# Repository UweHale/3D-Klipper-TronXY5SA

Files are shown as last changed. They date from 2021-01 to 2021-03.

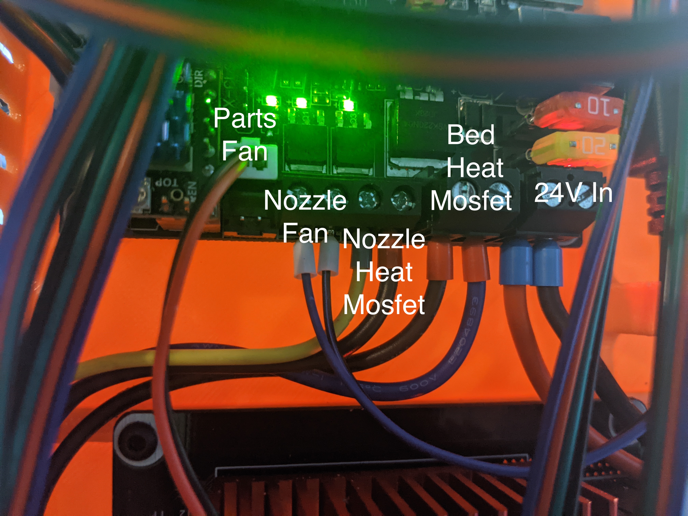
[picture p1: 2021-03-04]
SKR-Power-Fan.jpg

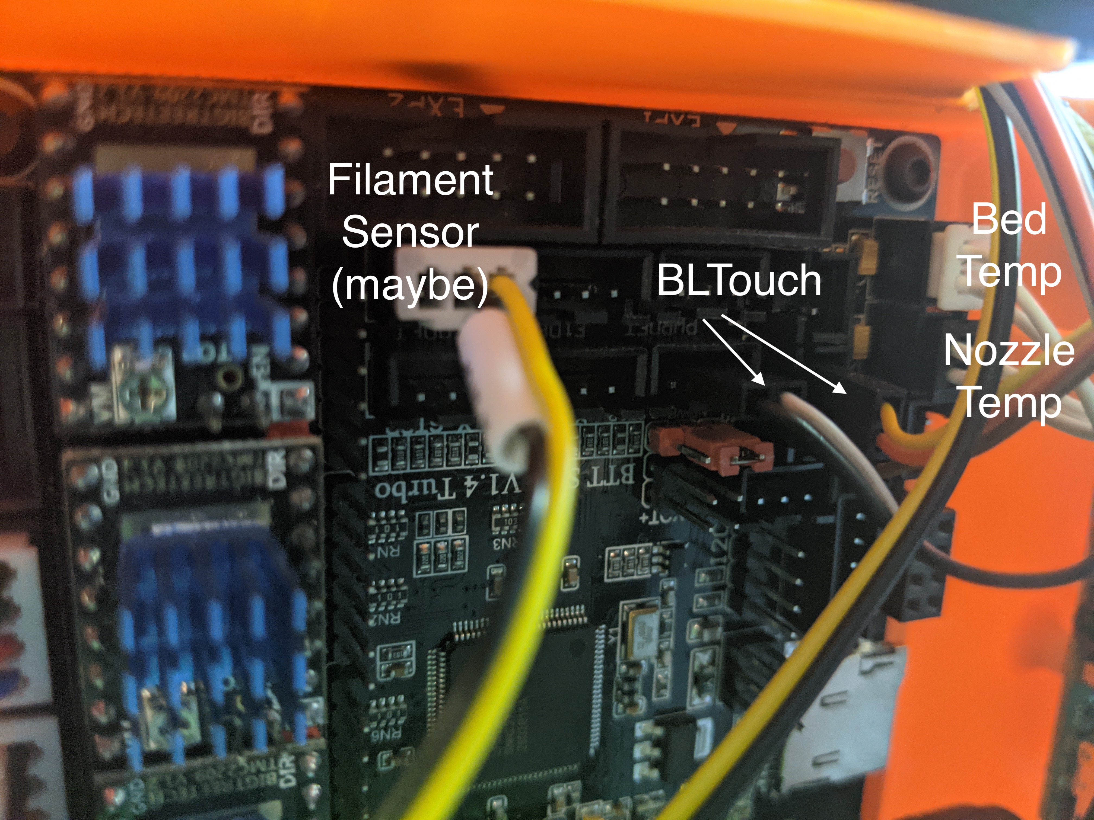
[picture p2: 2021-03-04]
SKR-Sensors.jpg

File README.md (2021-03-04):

# 3D-Klipper-TronXY5SA

Modifying a TronXY5SA to use a SKR 1.4 Turbo board and a Raspberry PI running OctoPi and Klipper.

STL and Fusion 360 file for a custom case to hold it all.

Be sure you have good thermal control.  The case can warp and lift off the bed if cooled too rapidly.  You might need to turn on supports for the corner screw blocks for a lid.

The Z adjust blocks are spacers for doing the initial Z sync on the stepper motors.  Put one on each side and bottom out (stall the motors) the bed rails.  Lower bed, remove and continue 

Carriage bracket for BMG Direct Extruder and a Dragon Hotend with BLTouch.

Use supports for the parts fan.  The BMG extruder mount does not need supports.  I printed mine with PETG. 

Power supply is a MEAN WELL RSP-500-24
https://smile.amazon.com/gp/product/B00UWCD22O

Designed with 50mm centrifugal fans from Winsinn
https://smile.amazon.com/gp/product/B07DB7DLMM

BCZAMD 3D Printer Heating Controller MKS MOSFET
https://smile.amazon.com/gp/product/B07R292KXF

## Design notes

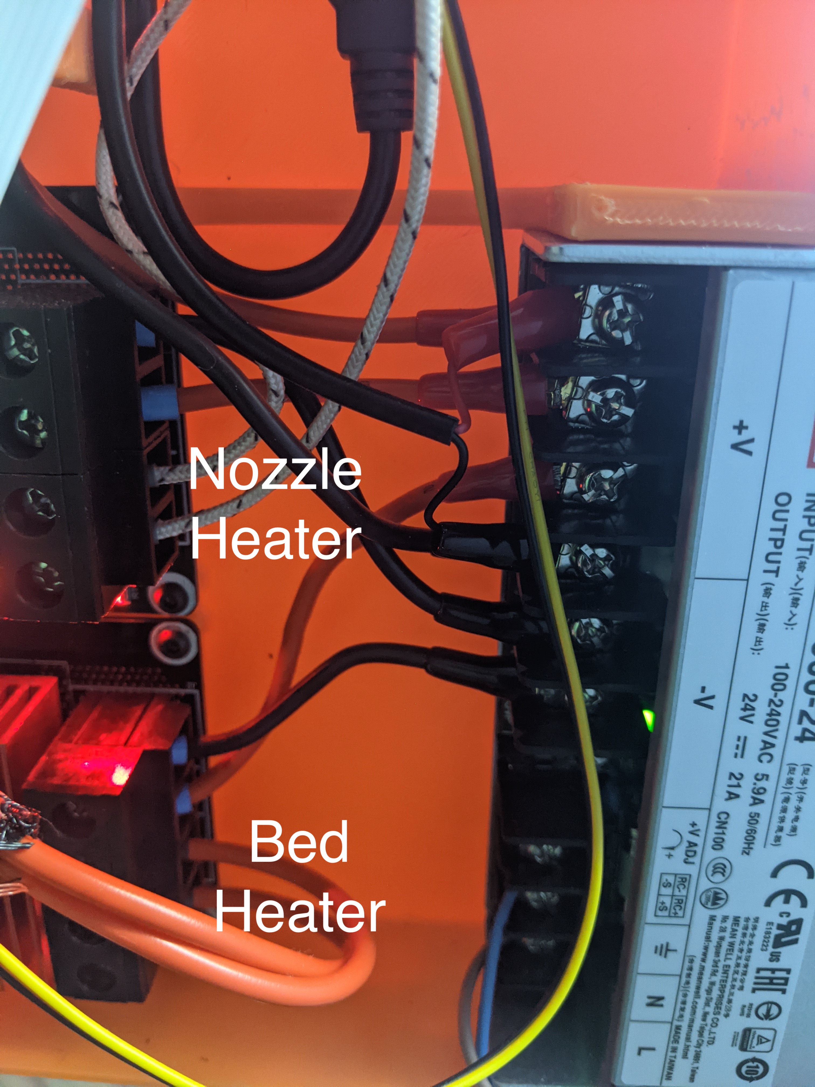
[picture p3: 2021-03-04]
Mosfet-Power.jpg

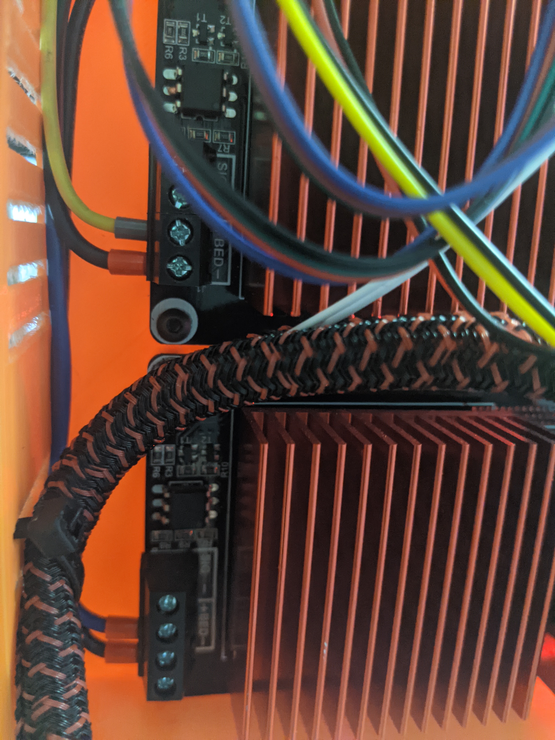
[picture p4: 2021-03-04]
Mosfet-Control.jpg

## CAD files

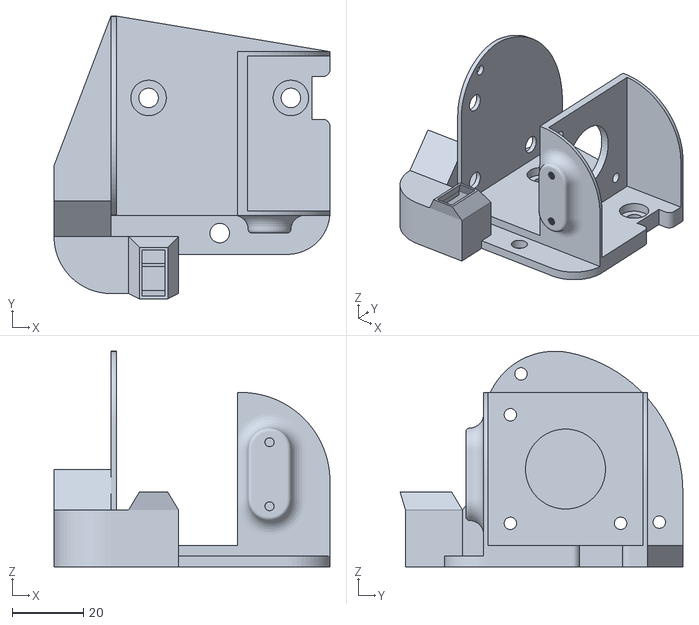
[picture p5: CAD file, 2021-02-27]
TronXY-BMG-Mount.stl
77.6 x 79.5 x 60.6

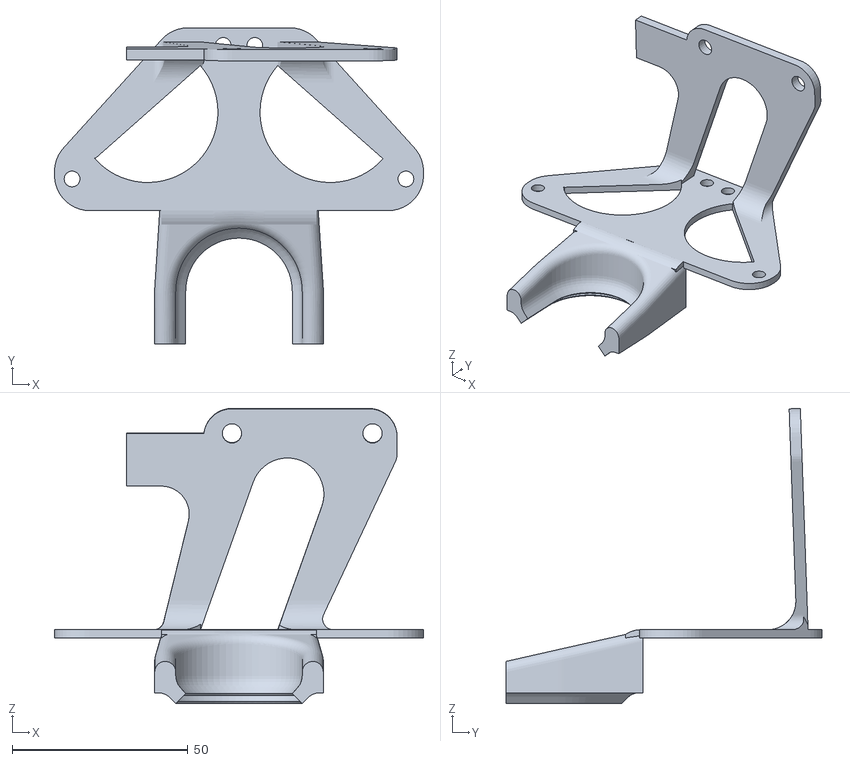
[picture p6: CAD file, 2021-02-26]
PartsFanSmall.stl
105.0 x 90.0 x 84.0

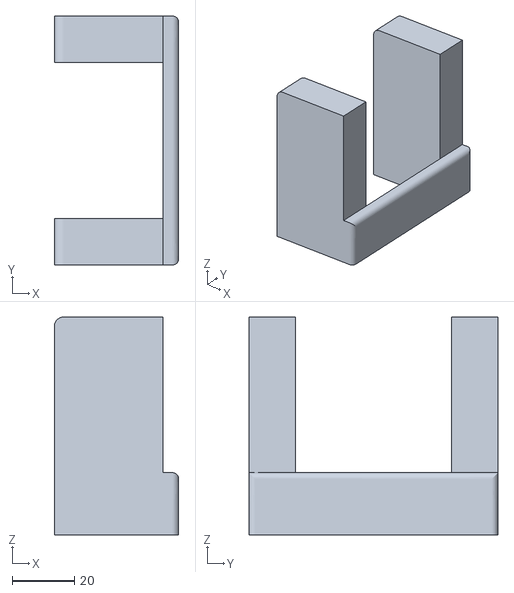
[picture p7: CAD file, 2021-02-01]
Z-AdjustBlock.stl
40.0 x 80.0 x 70.0

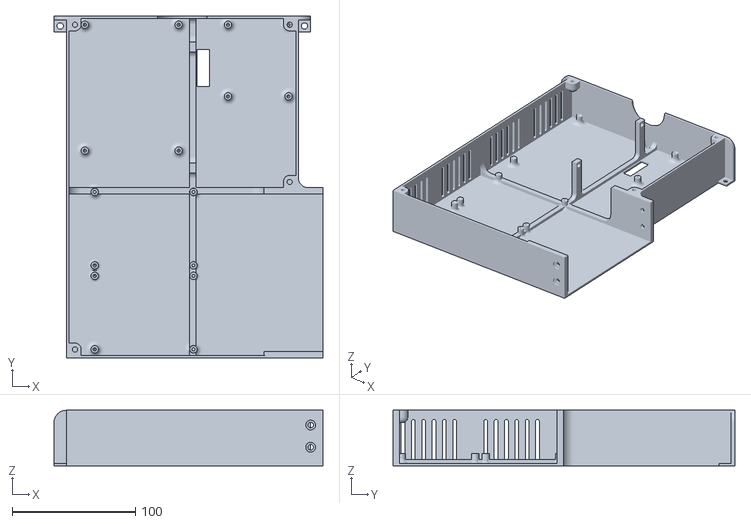
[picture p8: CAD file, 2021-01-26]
3DCaseV19.stl
218.0 x 277.0 x 45.0

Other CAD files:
PartsFanSmall.f3d
TronXY-BMG-Mount.f3d
Z-AdjustBlock.f3d

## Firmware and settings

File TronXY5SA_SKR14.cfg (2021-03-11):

# This file contains common pin mappings for the BIGTREETECH SKR V1.4# This file contains common pin mappings for the BIGTREETECH SKR V1.4
# board. To use this config, the firmware should be compiled for the
# LPC1768 or LPC1769(Turbo).

# See the example.cfg file for a description of available parameters.

[mcu]
serial: /dev/serial/by-id/usb-Klipper_lpc1769_06C0FF1047084AAFC2D66C5DC12000F5-if00

[printer]
kinematics: corexy
max_velocity: 200
max_accel: 2000
max_z_velocity: 25
max_z_accel: 30

[gcode_macro G29]
gcode:
 G28
 BED_MESH_CALIBRATE
 G1 X160 Y160 Z30

[gcode_arcs]
resolution: 0.01

[fan]
pin: P2.3

[heater_fan nozzle_fan]
pin: P2.4
heater: extruder
heater_temp: 50.0 
#idle_timeout: 600

[filament_switch_sensor my_filament_sensor]
switch_pin: P1.26

[stepper_x]
step_pin: P2.2
dir_pin: P2.6
enable_pin: !P2.1
microsteps: 16
rotation_distance: 40
endstop_pin: tmc2209_stepper_x:virtual_endstop 
position_endstop: -1
position_max: 330
position_min: -1
homing_speed: 40.0
homing_retract_dist: 0

[stepper_y]
step_pin: P0.19
dir_pin: P0.20
enable_pin: !P2.8
microsteps: 16
rotation_distance: 40
endstop_pin: tmc2209_stepper_y:virtual_endstop 
position_endstop: -1
position_max: 320
position_min: -1
homing_speed: 40.0
homing_retract_dist: 0

[stepper_z]
step_pin: P0.22
dir_pin: !P2.11
enable_pin: !P0.21
microsteps: 16
rotation_distance: 8
endstop_pin: probe:z_virtual_endstop
position_max: 400
position_min: -15

[safe_z_home]
home_xy_position: 160,160 # Change coordinates to the center of your print bed
speed: 50
z_hop: 10          
z_hop_speed: 20

[bltouch]
control_pin: P2.0 #ok
#sensor_pin: P0.10 # The built in pin for blt does not work
sensor_pin: P1.27 # z-stop works
x_offset: 32
y_offset: 5
#z_offset: 1
pin_move_time: 1
#pin_up_touch_mode_reports_triggered: False
samples: 3


[bed_mesh]
speed: 100
horizontal_move_z: 10
mesh_min: 42,25
mesh_max: 320, 310
probe_count: 6,6


[extruder]
step_pin: P2.13
dir_pin: !P0.11
enable_pin: !P2.12
microsteps: 16
rotation_distance: 22
gear_ratio: 50:17
nozzle_diameter: 0.400
filament_diameter: 1.750
heater_pin: P2.7
sensor_type: ATC Semitec 104GT-2
sensor_pin: P0.24
control: pid
pid_Kp=20.137
pid_Ki=0.814
pid_Kd=124.599
min_temp: 0
max_temp: 295
max_extrude_only_distance: 300

[heater_bed]
heater_pin: P2.5
sensor_type: EPCOS 100K B57560G104F
sensor_pin: P0.25
control: pid
min_temp: 0
max_temp: 130
pid_Kp=70.186
pid_Ki=1.147
pid_Kd=1073.839



########################################
# TMC2209 configuration
########################################

[tmc2209 stepper_x]
uart_pin: P1.10
run_current: 0.800
hold_current: 0.500
stealthchop_threshold: 120
diag_pin: P1.29
driver_SGTHRS: 100#related to homing speed
#
[tmc2209 stepper_y]
uart_pin: P1.9
run_current: 0.800
hold_current: 0.500
stealthchop_threshold: 120
diag_pin: P1.28
driver_SGTHRS: 100#related to homing speed
#
[tmc2209 stepper_z]
uart_pin: P1.8
run_current: 0.650
hold_current: 0.450
stealthchop_threshold: 30
#
[tmc2209 extruder]
uart_pin: P1.4
run_current: 0.650
hold_current: 0.450
stealthchop_threshold: 5


########################################
# EXP1 / EXP2 (display) pins
########################################

[board_pins]
aliases:
    # EXP1 header
    EXP1_1=P1.30, EXP1_3=P1.18, EXP1_5=P1.20, EXP1_7=P1.22, EXP1_9=<GND>,
    EXP1_2=P0.28, EXP1_4=P1.19, EXP1_6=P1.21, EXP1_8=P1.23, EXP1_10=<5V>,
    # EXP2 header
    EXP2_1=P0.17, EXP2_3=P3.26, EXP2_5=P3.25, EXP2_7=P1.31, EXP2_9=<GND>,
    EXP2_2=P0.15, EXP2_4=P0.16, EXP2_6=P0.18, EXP2_8=<RST>, EXP2_10=<NC>
    # Pins EXP2_1, EXP2_6, EXP2_2 are also MISO, MOSI, SCK of bus "ssp0"

# See the sample-lcd.cfg file for definitions of common LCD displays.

#*# <---------------------- SAVE_CONFIG ---------------------->
#*# DO NOT EDIT THIS BLOCK OR BELOW. The contents are auto-generated.
#*#
#*# [bed_mesh default]
#*# version = 1
#*# points =
#*# 	  -0.440833, -0.430000, -0.460833, -0.429167, -0.442500, -0.478333
#*# 	  -0.303333, -0.275000, -0.242500, -0.192500, -0.191667, -0.200000
#*# 	  -0.195000, -0.144167, -0.116667, -0.118333, -0.106667, -0.115000
#*# 	  -0.207500, -0.125000, -0.135000, -0.120833, -0.130000, -0.199167
#*# 	  -0.268333, -0.239167, -0.258333, -0.206667, -0.261667, -0.202500
#*# 	  -0.435833, -0.465833, -0.464167, -0.468333, -0.406667, -0.449167
#*# x_count = 6
#*# y_count = 6
#*# mesh_x_pps = 2
#*# mesh_y_pps = 2
#*# algo = lagrange
#*# tension = 0.2
#*# min_x = 42.0
#*# max_x = 320.0
#*# min_y = 25.0
#*# max_y = 310.0
#*#
#*# [bltouch]
#*# z_offset = 2.899

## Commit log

2021-02-15 Update TronXY5SA_SKR14.cfg
    updated for BMG geared extruder and new carriage mount with relocated bltouch
    [TronXY5SA_SKR14.cfg]
2021-02-26 Add files via upload
    parts fan for dual 50mm centrifugal fans.
    [PartsFan.f3d, PartsFan.stl]
2021-02-27 Add files via upload
    Fixed one wall being a separate object
    [TronXY-BMG-Mount.f3d, TronXY-BMG-Mount.stl]
2021-03-04 Add files via upload
    pictures of wiring
2021-03-04 Update TronXY5SA_SKR14.cfg
    Moved nozzle fan to a controllable pin HE1
    [TronXY5SA_SKR14.cfg]
2021-03-11 Update TronXY5SA_SKR14.cfg
    converted from stepper_distance to rotation_distance.
    Added gearing for bmg
    [TronXY5SA_SKR14.cfg]
